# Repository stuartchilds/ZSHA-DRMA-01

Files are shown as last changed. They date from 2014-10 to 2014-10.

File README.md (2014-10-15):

ZSHA - DRMA-01
==============

Laser files designed by Stuart Childs shared under a Creative Commons Attribution-ShareAlike 3.0 Unported license, unless otherwise stated in the containing folders.

I hope you enjoy using these files and they enable you to make some cool stuff. 

---

DRMA is a two motor drawing machine inspired by many other machines of this design. I saw Matthew Venn messing around with a version of this and wanted to make one based on oomlout's OOBB design principle ( https://github.com/oomlout/oomlout-OOBB )

Matt Venn originally inspired by this machine: http://inventorartist.com/art-o-matic-v1/

I put time into this design so that I could run workshops for people - learning to solder the circuit board before getting to play with the machine and make some nice drawings.

Circuit board was designed by Matt Venn - find it here https://oshpark.com/shared_projects/GKjx5Y9X

Functionality
Circuit board allows for speed and direction control of 2x DC motors. Each motor intended to drive arms that can be linked in many ways creating pivots and levers moving on a large drawing surface.
Machine designed to hold pens and an A4 sheet of paper to create patterns. Physical output designed to stimulate experimentation and creativity.

---

B.O.M.

	- 1x MDF laser cut OOBB sheets (2 sheets total from 3mm MDF sheet stock)
	- 1x 9v battery or other power source (5v 1A power supply works well)
	- 4x 3mm nylon rivet (or M3 16mm nylon screw)
	- 4x M3 3mm nylon spacer (or 4x M3 nylon nuts)
	- 8x 300mm jumper wires
		- http://oomlout.co.uk/blogs/news/7869929-new-product-jumper-wires-premium-female-female-21-x-300-mm
	- 4x long header pins
		- http://oomlout.co.uk/products/long-headers-x4
	- 1x drawing machine circuit board
		- https://oshpark.com/shared_projects/GKjx5Y9X
	- 2x 10k potentiometer
		- http://oomlout.co.uk/products/potentiometer-10k-ohm-panel-mount
	- 2x potentiometer knobs (optional)
	- 2x DPDT push switches
		- http://www.ebay.co.uk/itm/Miniature-DPDT-Switch-5-per-order-2-00-Item-1015-NEW-/251500883626
	- 1x SPST on/off switch
		- http://uk.farnell.com/c-k-components/os102011ma1qn1/switch-spdt-0-1a-12v-pcb-r-a/dp/1201431?Ntt=1201431
	- 2x LM317 motor driver IC
		- http://uk.farnell.com/texas-instruments/lm317lclp/ic-adj-linear-reg-1-2v-to-32v-to/dp/2342553
	- 2x 10k ohm resistor
		- http://oomlout.co.uk/products/resistor-kit-resk-500-20-types
	- 1x LED
		- http://oomlout.co.uk/products/10mm-led-rainbow-pack
	- 1x 220 ohm resistor
		- http://oomlout.co.uk/products/resistor-kit-resk-500-20-types
	- 4x M3 25mm self tapping screws
	- 20x M6 nuts
	- 2x M6 connecting/long nuts
	- 20x M6 nylock nuts
	- 2x M6 8mm countersunk machine screws
	- 20x M6 12mm hex head bolts
	- 10x M6 16mm hex head bolts
	- 8x M6 30mm hex head bolts
---

(all hardware - screw, nuts and bolts ordered from http://www.orbitalfasteners.co.uk/ - my favourite online hardware supplier for bulk buys)

---
Brief assembly notes

- solder components to circuit board
- cut one end off each jumper wire
- solder 9v battery clip or power source leads to circuit board
- solder 4x jumper wires to M1+,M1-,M2+,M2- terminals on circuit board
- solder 2x jumper wires to each motor
- use plastic rivets and spacers (or screws and nuts) to mount circuit board to OOBB mounting plate
- use self tapping screws (2 per motor) to attach motors to OOBB mounting plates
- choose position of circuit board and motor mounting plates onto drawing board and use 2x M6 12mm bolts and M6 nuts to attach each plate to main drawing board
- attach 1x countersunk screw and M6 connecting nut to 2 OOBB circles
- press one OOBB circle with screw and nut onto each motor drive spindle
- use 2x long header pins to connect each motor to circuit board and test that board works. 
- attach long OOBB arms to motor circles using M6 30mm bolts - finger tight to stop bolts working loose
- add more OOBB arms as desired - including pivot points and overlapping parts. Avoid triangles that prevent free movement of arms. Use M6 12mm bolts with M6 nylock nuts to allow for quick assembly of pivot points that don't work loose.
- build pen holder
- attach pen
- attach paper to drawing board
- experiment and draw!

---
Some photos of assembled machines: https://www.flickr.com/photos/stuartchilds/sets/72157646454106094

----
Mad props to:

Creative Commons

Oomlout.co.uk

Matt Venn

The Zulu Nation

----

open your designs!

----

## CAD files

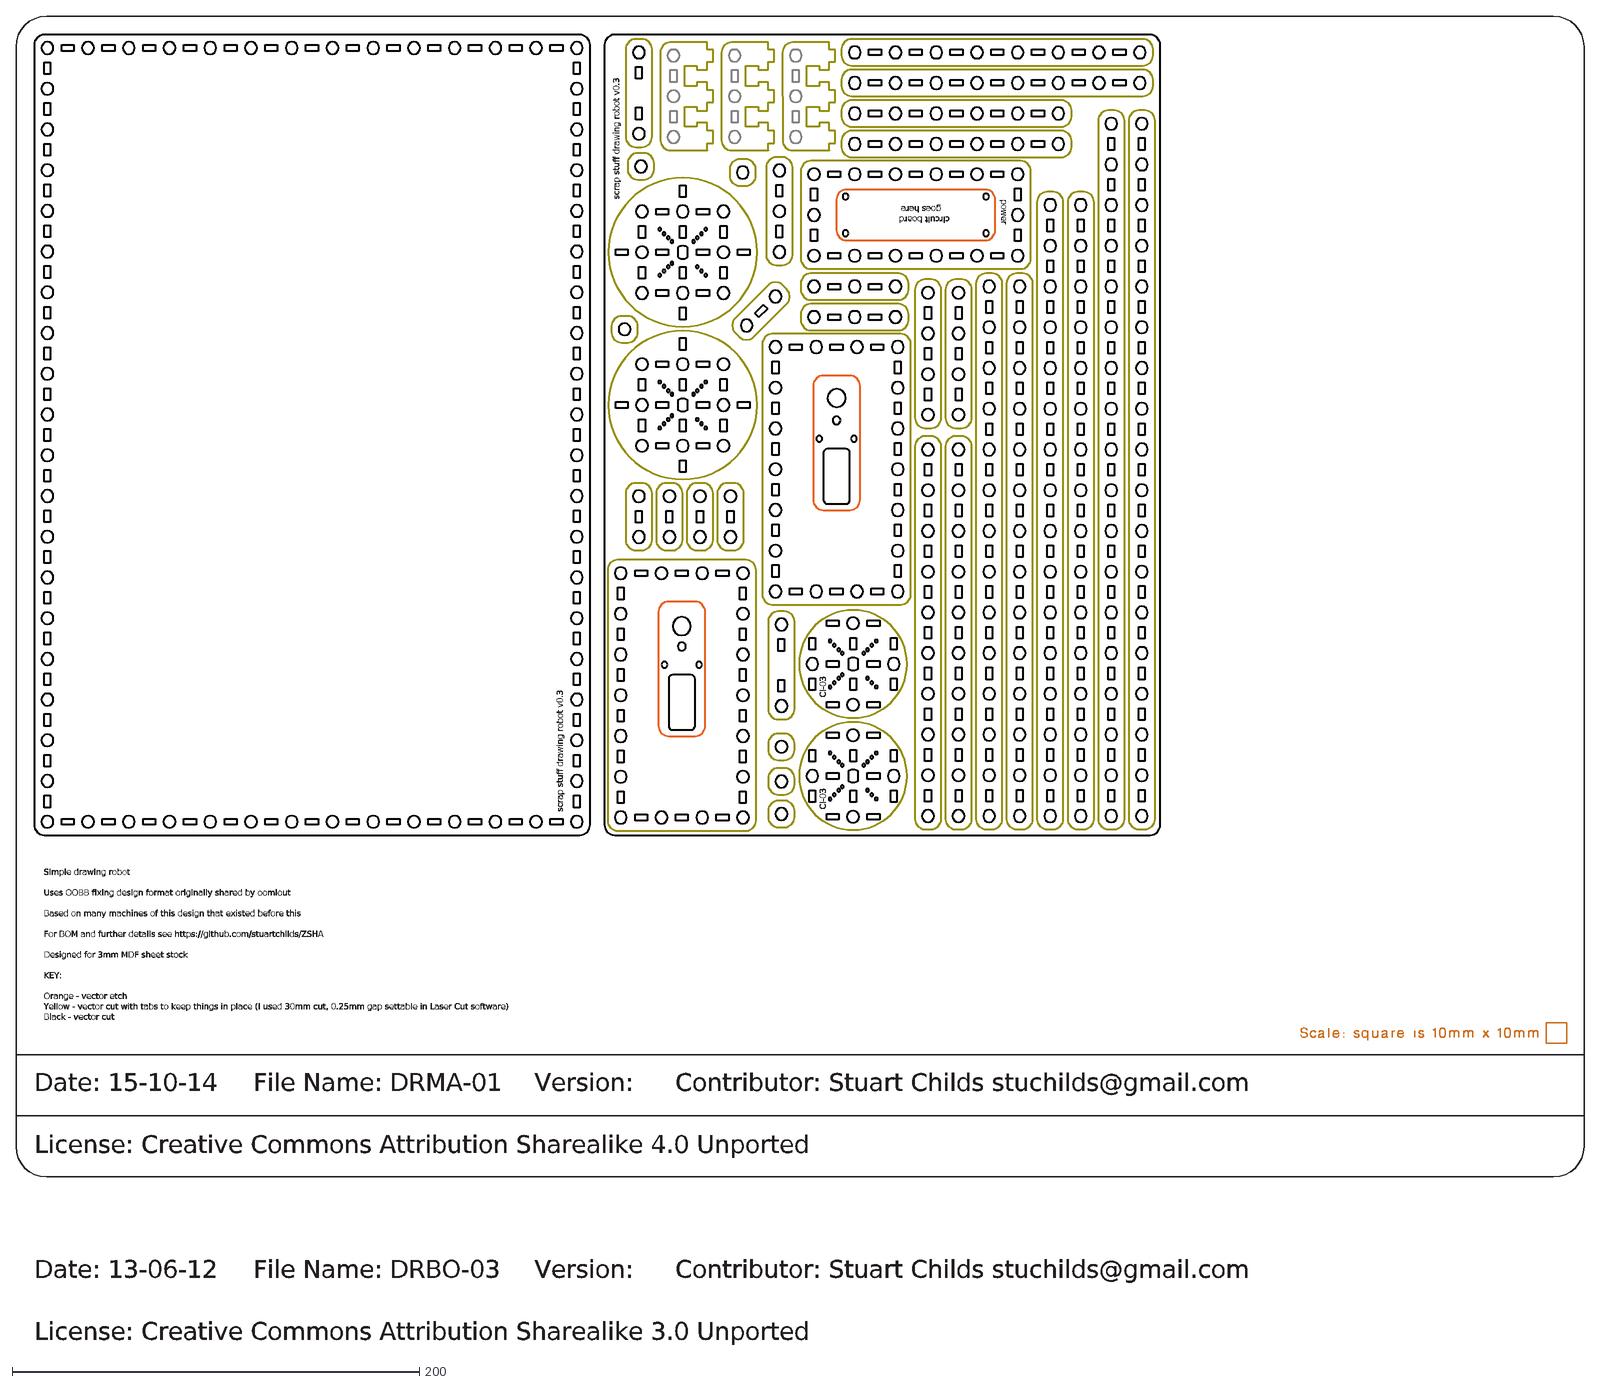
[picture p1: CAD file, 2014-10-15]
ZSHA-DRMA-01.dxf
Date: 13-06-12 File Name: DRBO-03 Version: Contributor: Stuart Childs stuchilds@gmail.com
License: Creative Commons Attribution Sharealike 3.0 Unported
Date: 15-10-14 File Name: DRMA-01 Version: Contributor: Stuart Childs stuchilds@gmail.com
License: Creative Commons Attribution Sharealike 4.0 Unported
Simple drawing robot
Uses OOBB fixing design format originally shared by oomlout
Based on many machines of this design that existed before this
For BOM and further details see https://github.com/stuartchilds/ZSHA
Designed for 3mm MDF sheet stock
KEY:
Orange - vector etch
Yellow - vector cut with tabs to keep things in place (I used 30mm cut, 0.25mm gap settable in Laser Cut software)
Black - vector cut
CI-03
scrap stuff drawing robot v0.3
power
circuit board
goes here

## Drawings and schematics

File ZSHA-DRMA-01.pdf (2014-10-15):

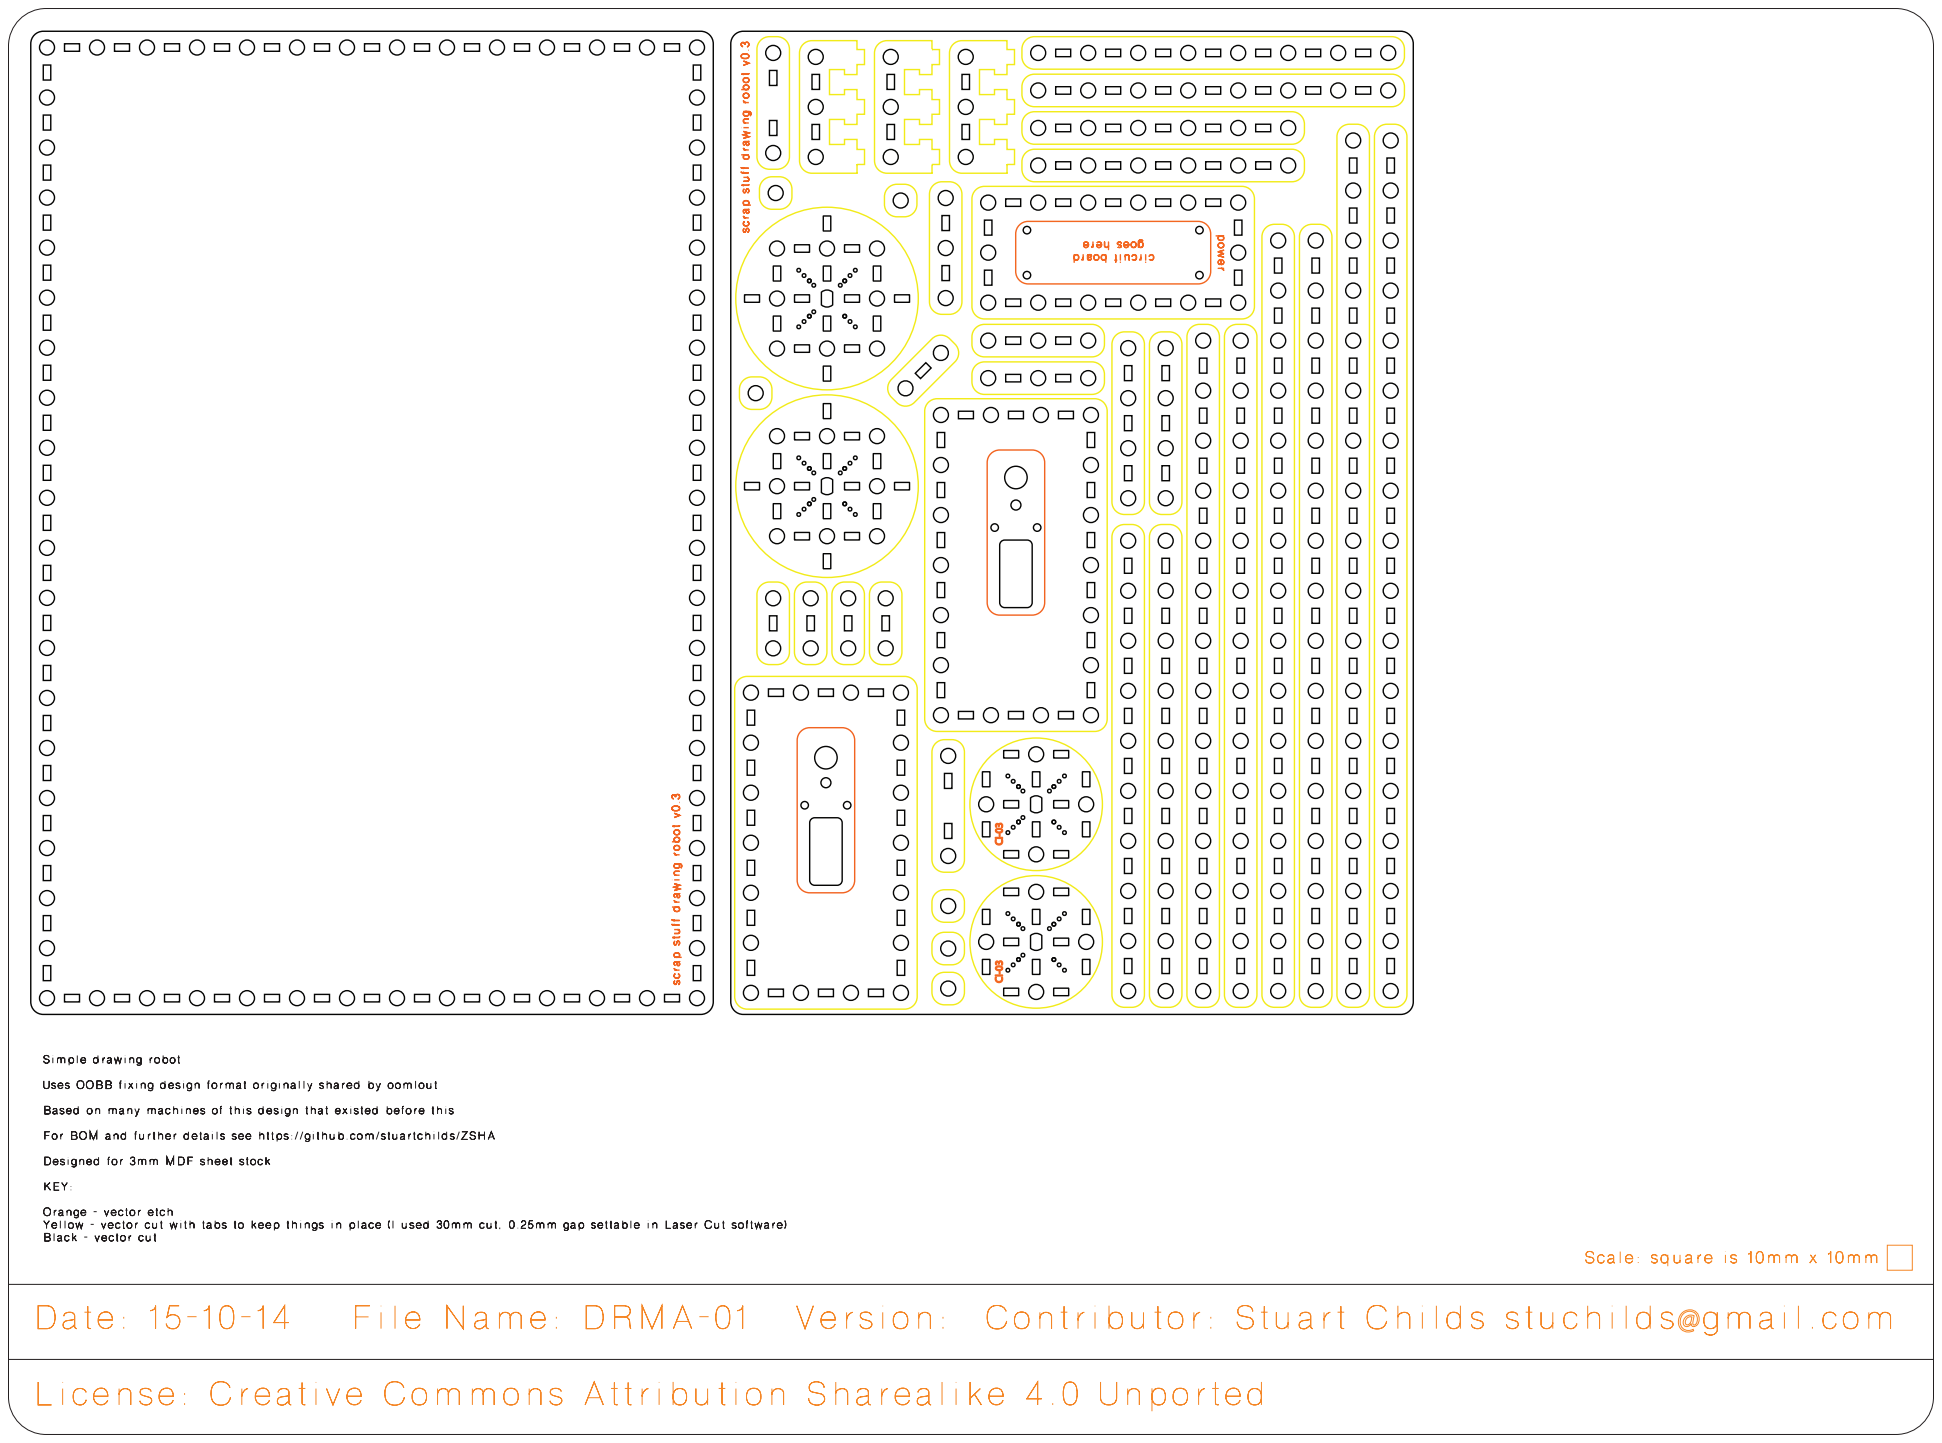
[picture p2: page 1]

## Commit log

2014-10-15 Adding laser files and readme
    [ZSHA-DRMA-01.dxf]
2014-10-15 Updating readme
    Adding links to circuit board and photos
2014-10-15 Adding links to BOM
    Adding links to BOM to help others source parts

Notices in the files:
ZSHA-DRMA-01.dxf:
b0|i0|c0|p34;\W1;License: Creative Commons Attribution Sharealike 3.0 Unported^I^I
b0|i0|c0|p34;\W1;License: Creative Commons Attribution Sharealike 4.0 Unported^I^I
